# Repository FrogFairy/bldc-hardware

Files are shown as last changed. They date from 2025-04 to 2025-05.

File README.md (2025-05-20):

## Schematic top level
new

## Layout -made with KiCad!-
Layout

## 3D views
3D_1
3d_2

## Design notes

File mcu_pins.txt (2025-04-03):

LED_GREEN PC4 -> PC8
LED_RED PC5 -> PC9
RX_SCL_MOSI PA7 -> PC13
AN_IN PC2 -> PA7
TX_SDA_NSS PA4 -> PD2
TEMP_MOTOR PC0 -> PA4

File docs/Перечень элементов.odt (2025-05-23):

Поз. обозна- чение | Наименование | Кол. | Примечание
C1, C2 | Конденсатор керамический 100 нФ 0603 | 2
C3 | Конденсатор керамический 2.2 мкФ 0603 | 1
C4-C7 | Конденсатор керамический 4.7 нФ 0603 | 4
C8 | Конденсатор керамический 2.2 мкФ 0603 | 1
C9 | Конденсатор керамический 15 пФ 0603 | 1
C10-C12 | Конденсатор керамический 2.2 мкФ 0603 | 3
C13 | Конденсатор керамический 100 нФ 0603 | 1
C14 | Конденсатор керамический 2.2 мкФ 0603 | 1
C15 | Конденсатор керамический 15 пФ 0603 | 1
C16-C22 | Конденсатор керамический 2.2 мкФ 0603 | 7
C23 | Конденсатор керамический 120 пФ 0603 | 1
C24, C25 | Конденсатор керамический 2.2 мкФ 0603 | 2
C26 | Конденсатор керамический 6.8 нФ 0603 | 1
C27 | Конденсатор керамический 22 нФ 0603 | 1
C28 | Конденсатор керамический 2.2 мкФ 0603 | 1
C29-C31 | Конденсатор керамический 10 мкФ 50В 1206 | 3
C32 | Конденсатор керамический 100 нФ 0603 | 1
C33-C35 | Конденсатор крамический 220 нФ X7R 0603 | 3
C36, C37 | Конденсатор керамический 2.2 нФ 0603 | 2
C38 | Конденсатор керамический 2.2 мкФ 0603 | 1
C39 | Конденсатор танталовый 100 мкФ 10В | 1
C40 | Конденсатор керамический 10 мкФ 50В 1206 | 1
C41 | Конденсатор танталовый 100 мкФ 10В | 1
C42, C43 | Конденсатор керамический 10 мкФ 50В 1206 | 2
C44 | Конденсатор керамический 15 мкФ 100В 2220 | 1
C45, C46 | Конденсатор керамический 10 мкФ 50В 1206 | 2
C47 | Конденсатор керамический 15 мкФ 100В 2220 | 1
C48-C53 | Конденсатор керамический 100 нФ 0603 | 6
D1 | Светодиод красный 0603 | 1
D2 | Светодиод зелёный 0603 | 1
D3 | Светодиод жёлтый 0603 | 1
D4 | Диод Шоттки 1N5819 | 1
D5 | Защитный диод SMAJ7.0A | 1
D7 | Диод Шоттки SS24 SMA | 1
J1 | Разъём ST BM10B-GHS-TBT 10-pin | 1
J2 | Разъём USB Type-C | 1
K1 | Разъём сервопривода 3-pin | 1
L1 | Дроссель 22 мкГн 8x5 мм | 1
P1 | Разъём B4B-PH-K(LF)(SN) | 1
P2 | Разъём датчика угла JST-6 | 1
P3 | Клеммник питания B7B-PH-KL | 1
P4 | Клеммник входа "+" | 1
P5 | Клеммник входа "-" | 1
P6 | Клеммник подключения двигателя 3 | 1
P7 | Клеммник подключения двигателя 2 | 1
P8 | Клеммник подключения двигателя 1 | 1
P9 | Разъём питания JST-6 | 1
Q1-Q6 | Транзистор IRFS7530TRLPBF | 6
R1 | Чип резистор 39 кОм 0603 5% | 1
R2 | Чип резистор 2.2 кОм 0603 1% | 1
R6, R7 | Чип резистор 100 Ом 0603 1% | 2
R8, R9 | Чип резистор 2.2 кОм 0603 1% | 2
R10, R11 | Резистор-шунт 0 Ом 2 Вт | 2
R12 | Резистор-перемычка 0 Ом 0603 | 1
R13, R14 | Чип резистор 10 кОм 0603 1% | 2
R15-R17 | Чип резистор 2.2 кОм 0603 1% | 3
R18-R20 | Чип резистор 10 кОм 0603 1% | 3
R21 | Термистор NTC 10 кОм 0603 | 1
R22 | Чип резистор 10 кОм 0603 1% | 1
R23 | Чип резистор 18 кОм 0603 1% | 1
R24 | Чип резистор 3.3 кОм 0603 1% | 1
R25 | Чип резистор 10 кОм 0603 1% | 1
R26 | Чип резистор 15 кОм 0603 5% | 1
R27 | Чип резистор 220 кОм 0603 5% | 1
R28 | Чип резистор 1 МОм 0603 1% | 1
R29-R32 | Чип резистор 100 Ом 0603 1% | 4
R33 | Чип резистор 39 кОм 0603 5% | 1
R34 | Чип резистор 2.2 кОм 0603 1% | 1
R35 | Чип резистор 39 кОм 0603 5% | 1
R36 | Чип резистор 2.2 кОм 0603 1% | 1
R37 | Чип резистор 39 кОм 0603 5% | 1
R38 | Чип резистор 2.2 кОм 0603 1% | 1
R39, R40 | Чип резистор 4.7 Ом 0603 1% | 2
R41 | Чип резистор 39 кОм 0603 5% | 1
R42, R43 | Чип резистор 4.7 Ом 0603 1% | 2
R44 | Чип резистор 39 кОм 0603 5% | 1
R45, R46 | Чип резистор 4.7 Ом 0603 1% | 2
R47 | Чип резистор 39 кОм 0603 5% | 1
R48-R53 | Чип резистор 18 кОм 0603 1% | 6
R54-R59 | Чип резистор 2.2 кОм 0603 1% | 6
R60-R65 | Чип резистор 360 Ом 0603 1% | 6
R66-R71 | Чип резистор 16 Ом 2512 1% | 6
R103, R104 | Чип резистор 5.1 кОм 0603 | 2
U1 | CAN приёмопередатчик SN65HVD232DR | 1
U2 | Микроконтроллер STM32F40X LQFP64 | 1
U3 | Драйвер двигателя DRV8302DCA | 1
U4 | Стабилизатор напряжения TC2117 | 1
U11-U16 | Опто твердотельное реле CPC1002N 0603 | 6
X2 | Кварцевый резонатор 8 МГц 10ppm | 1

BLDC Driver 4.11 Перечень элементов Benjamin Vedder Лит. Лист 1 Листов 4 Разраб. Пров. Н. контр. Утв. Top level Изм. Лист № докум. Подп. Дата Инв. № подл. Подп. и дата Взам. инв. № Инв. № дубл. Подп. и дата Копировал Формат А4

BLDC Driver 4.11 Перечень элементов Benjamin Vedder Лит. Лист 0 Листов 4 Разраб. Пров. Н. контр. Утв. Top level Изм. Лист № докум. Подп. Дата Инв. № подл. Подп. и дата Взам. инв. № Инв. № дубл. Подп. и дата Справ. № Перв. примен. Копировал Формат А4

BLDC Driver 4.11 Перечень элементов Benjamin Vedder Лит. Лист 0 Листов 4 Разраб. Пров. Н. контр. Утв. Top level Изм. Лист № докум. Подп. Дата Инв. № подл. Подп. и дата Взам. инв. № Инв. № дубл. Подп. и дата Копировал Формат А4

Лист 4 Изм. Лист № докум. Подп. Дата Инв. № подл. Подп. и дата Взам. инв. № Инв. № дубл. Подп. и дата Копировал Формат А4

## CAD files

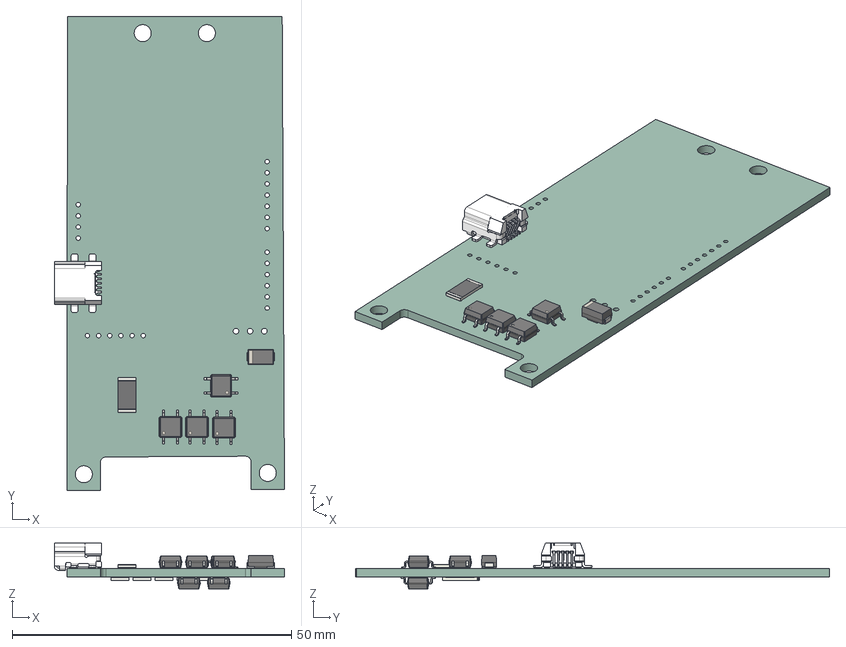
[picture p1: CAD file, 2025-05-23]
design/BLDC_4.step
41.2 x 85.0 x 8.23 mm
UX60R-MB-5ST-STEP
R_2512_6332Metric x 6
SOP-4_3.8x4.1mm_P2.54mm x 6
D_SMA
BLDC_4_PCB

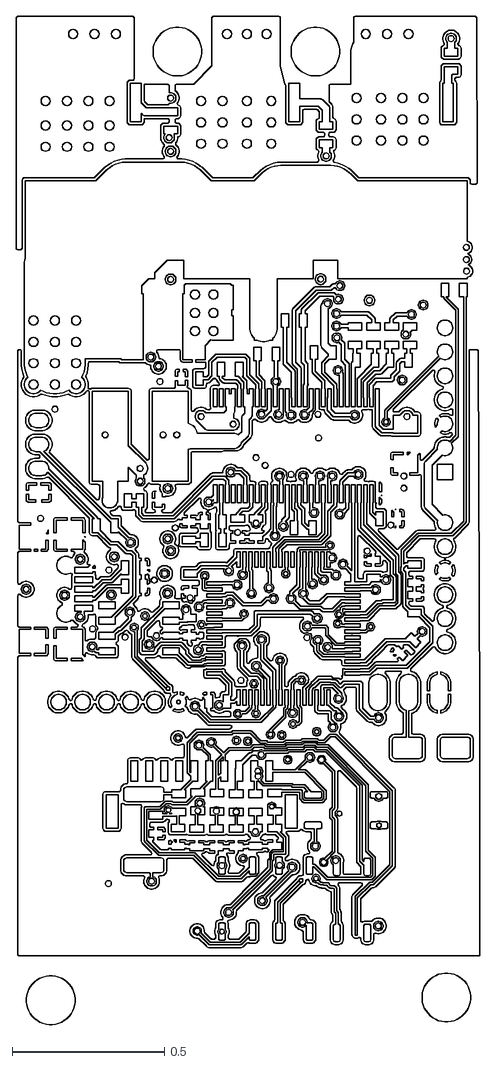
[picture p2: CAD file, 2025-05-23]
design/Gerber/BLDC_4-F_Cu.dxf
1.52 x 3.31

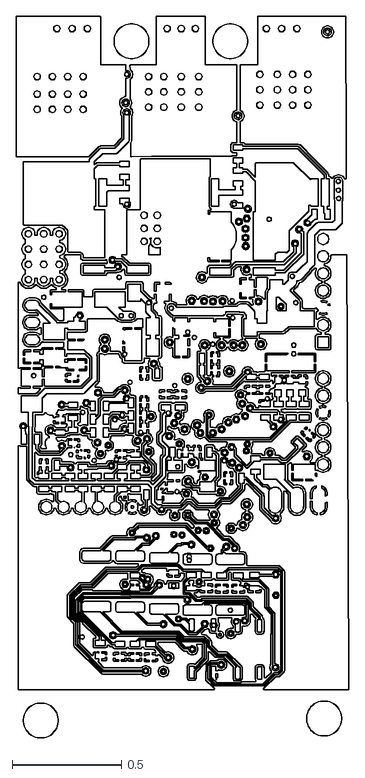
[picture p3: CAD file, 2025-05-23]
design/Gerber/BLDC_4-B_Cu.dxf
1.53 x 3.31

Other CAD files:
design/BLDC_4.stl
design/Gerber/BLDC_4-F_Silkscreen.dxf

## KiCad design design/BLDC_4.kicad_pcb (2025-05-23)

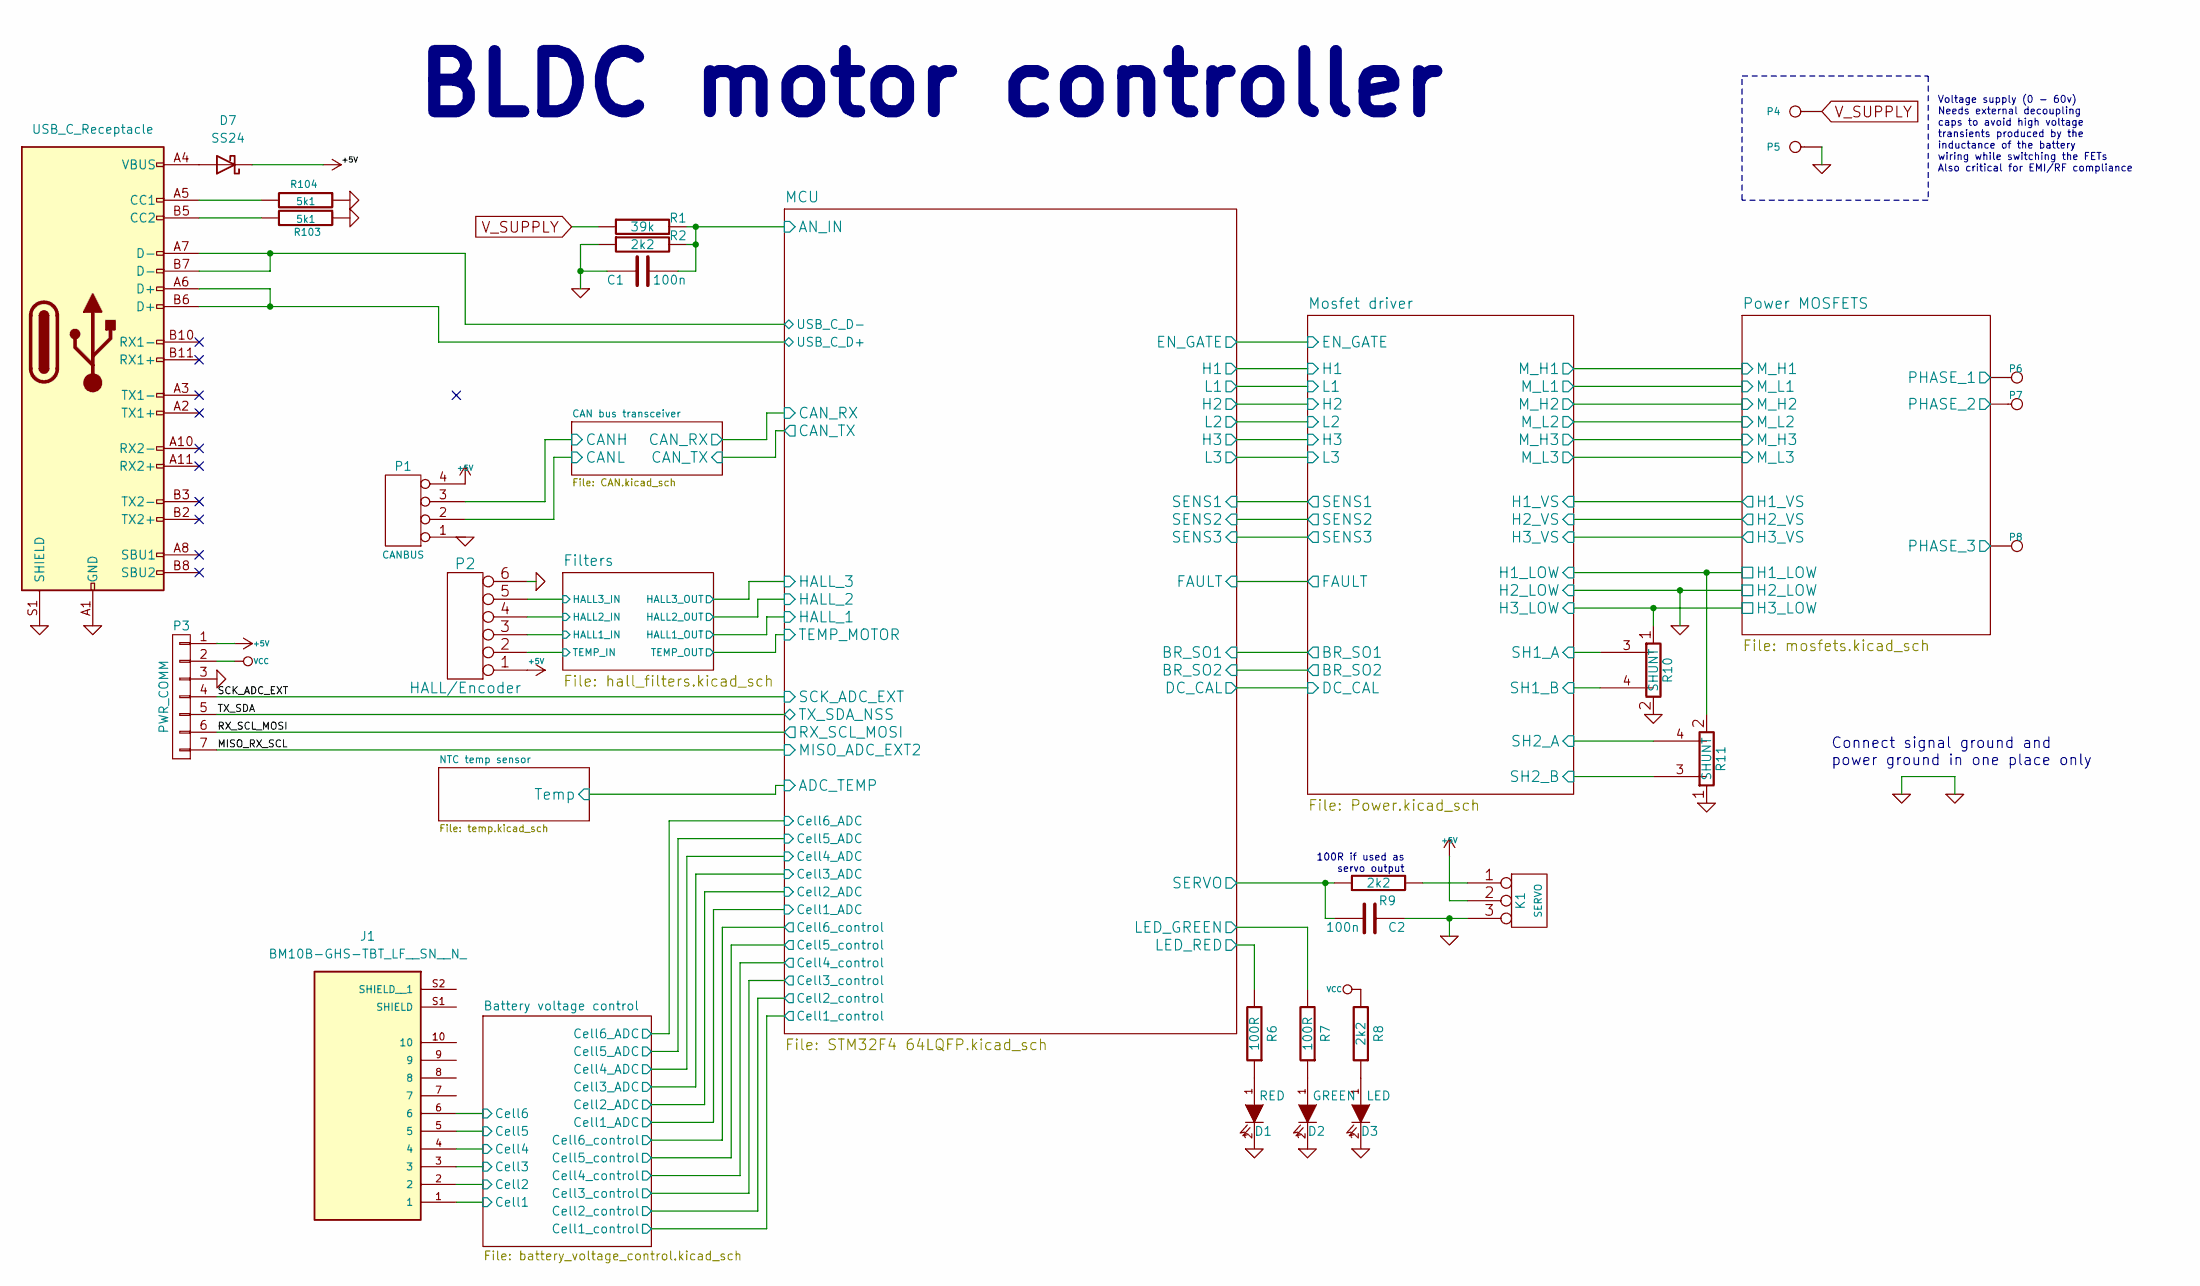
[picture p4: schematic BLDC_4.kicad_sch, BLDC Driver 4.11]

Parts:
C1, C2: 100n; SMD-0603_c
D1: RED; LED-0603
D2: GREEN; LED-0603
D3: LED; LED-0603
D7: SS24; D_SMA
J1: BM10B-GHS-TBT_LF__SN__N_; JST_BM10B-GHS-TBT_LF__SN__N_; PARTREV N/A
J2: USB_C_Receptacle
K1: SERVO; pinhead-1X03
P1: CANBUS; b4b-ph-kl
P2: HALL/Encoder; MICRO_JST_6
P3: PWR_COMM; b7b-ph-kl
P4: IN+; 1PAD_4x5mm
P5: IN-; 1PAD_4x5mm
P6: MOTOR3; 1PAD_4x5mm
P7: MOTOR2; 1PAD_4x5mm
P8: MOTOR1; 1PAD_4x5mm
R1: 39k; SMD-0603_r
R2, R8, R9: 2k2; SMD-0603_r
R6, R7: 100R; SMD-0603_r
R10, R11: SHUNT; WSLP2726
R103, R104: 5k1; SMD-0603_r

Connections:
+5V: D7.1 (K), K1.2 (PM), P1.4, P2.1, P3.1; also elsewhere on the board
/Battery voltage control/Cell1: J1.1; also elsewhere on the board
/Battery voltage control/Cell2: J1.2; also elsewhere on the board
/Battery voltage control/Cell3: J1.3; also elsewhere on the board
/Battery voltage control/Cell4: J1.4; also elsewhere on the board
/Battery voltage control/Cell5: J1.5; also elsewhere on the board
/Battery voltage control/Cell6: J1.6; also elsewhere on the board
/CAN bus transceiver/CANH: P1.3; also elsewhere on the board
/CAN bus transceiver/CANL: P1.2; also elsewhere on the board
/Filters/HALL1_IN: P2.3; also elsewhere on the board
/Filters/HALL2_IN: P2.4; also elsewhere on the board
/Filters/HALL3_IN: P2.5; also elsewhere on the board
/Filters/TEMP_MOTOR: P2.2; also elsewhere on the board
/MCU/AN_IN: C1.2, R1.2, R2.2; also elsewhere on the board
/MCU/LED_GREEN: R7.2; also elsewhere on the board
/MCU/LED_RED: R6.2; also elsewhere on the board
/MCU/SERVO: C2.2, R9.1; also elsewhere on the board
/MISO_RX_SCL: P3.7; also elsewhere on the board
/Mosfet driver/H1_LOW: R11.2; also elsewhere on the board
/Mosfet driver/H1_VS: P6.1; also elsewhere on the board
/Mosfet driver/H2_VS: P7.1; also elsewhere on the board
/Mosfet driver/H3_LOW: R10.1; also elsewhere on the board
/Mosfet driver/H3_VS: P8.1; also elsewhere on the board
/Mosfet driver/SH1_A: R10.3; also elsewhere on the board
/Mosfet driver/SH1_B: R10.4; also elsewhere on the board
/Mosfet driver/SH2_A: R11.4; also elsewhere on the board
/Mosfet driver/SH2_B: R11.3; also elsewhere on the board
/RX_SCL_MOSI: P3.6; also elsewhere on the board
/SCK_ADC_EXT: P3.4; also elsewhere on the board
/TX_SDA: P3.5; also elsewhere on the board
GND: C1.1, C2.1, D1.2 (K), D2.2 (K), D3.2 (K), J2.A1 (GND), J2.A12 (GND), J2.B1 (GND), J2.B12 (GND), J2.S1 (SHIELD), K1.3, P1.1, P2.6, P3.3, P5.1, R2.1, R10.2, R11.1, R103.1, R104.1; also elsewhere on the board
unnamed: D1.1 (A), R6.1
unnamed: D2.1 (A), R7.1
unnamed: D3.1 (A), R8.1
unnamed: D7.2 (A), J2.A4 (VBUS), J2.A9 (VBUS), J2.B4 (VBUS), J2.B9 (VBUS)
unnamed: J2.A5 (CC1), R104.2
unnamed: J2.B5 (CC2), R103.2
unnamed: J2.A6 (D+), J2.B6 (D+)
unnamed: J2.A7 (D-), J2.B7 (D-)
unnamed: K1.1, R9.2
VCC: P3.2, R8.2; also elsewhere on the board
V_SUPPLY: P4.1, R1.1; also elsewhere on the board

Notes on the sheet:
Voltage supply (0 - 60v) Needs external decoupling caps to avoid high voltage transients produced by the inductance of the battery wiring while switching the FETs Also critical for EMI/RF compliance
Connect signal ground and power ground in one place only
BLDC motor controller
100R if used as servo output

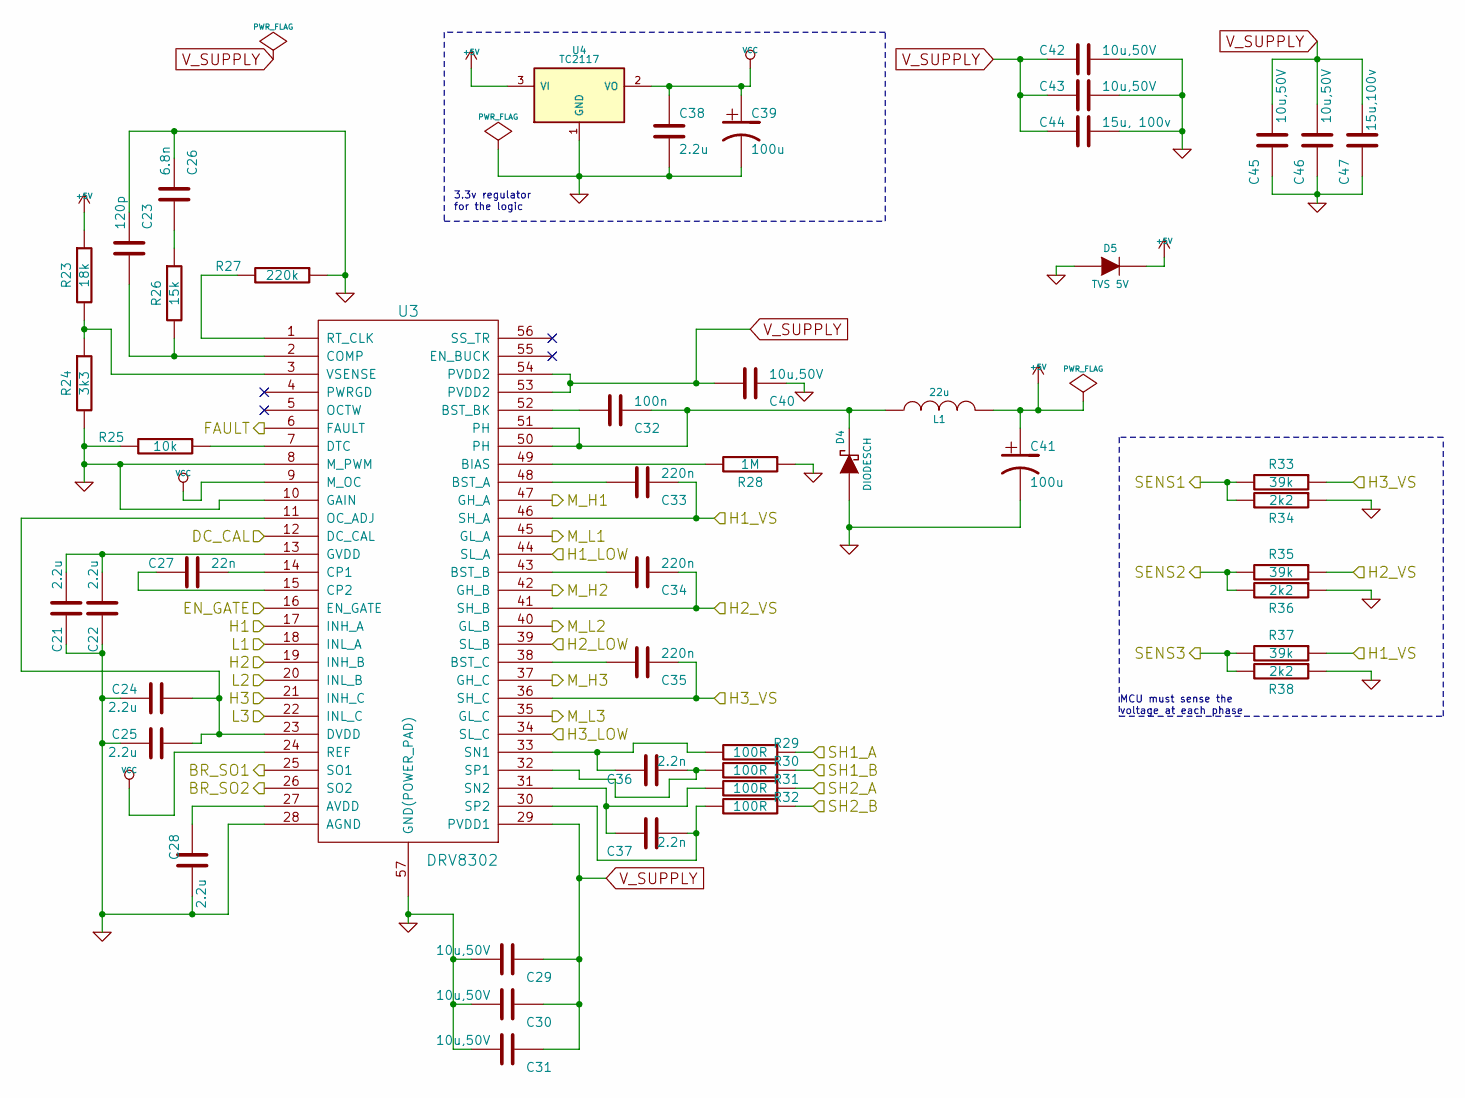
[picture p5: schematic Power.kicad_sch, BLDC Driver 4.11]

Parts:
C21, C22, C24, C25, C28, C38: 2.2u; SMD-0603_c
C23: 120p; SMD-0603_c
C26: 6.8n; SMD-0603_c
C27: 22n; SMD-0603_c
C29, C30, C31, C40, C42, C43, C45, C46: 10u,50V; SMD-1206
C32: 100n; SMD-0603_c
C33, C34, C35: 220n; SMD-0603_c
C36, C37: 2.2n; SMD-0603_c
C39, C41: 100u; c_tant_B
C44: 15u, 100v; c_2220
C47: 15u,100v; c_2220
D4: DIODESCH; SMA_Handsoldering
D5: TVS 5V; do214ac
L1: 22u; inductor_smd_8x5mm
R23: 18k; SMD-0603_r
R24: 3k3; SMD-0603_r
R25: 10k; SMD-0603_r
R26: 15k; SMD-0603_r
R27: 220k; SMD-0603_r
R28: 1M; SMD-0603_r
R29, R30, R31, R32: 100R; SMD-0603_r
R33, R35, R37: 39k; SMD-0603_r
R34, R36, R38: 2k2; SMD-0603_r
U3: DRV8302; TSSOP-56-PP
U4: TC2117; SOT-223

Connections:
+5V: C41.1, D5.2 (K), L1.2, R23.1, U4.3 (VI); also elsewhere on the board
/MCU/BR_SO1: U3.25 (SO1); also elsewhere on the board
/MCU/BR_SO2: U3.26 (SO2); also elsewhere on the board
/MCU/DC_CAL: U3.12 (DC_CAL); also elsewhere on the board
/MCU/EN_GATE: U3.16 (EN_GATE); also elsewhere on the board
/MCU/FAULT: U3.6 (FAULT); also elsewhere on the board
/MCU/H1: U3.17 (INH_A); also elsewhere on the board
/MCU/H2: U3.19 (INH_B); also elsewhere on the board
/MCU/H3: U3.21 (INH_C); also elsewhere on the board
/MCU/L1: U3.18 (INL_A); also elsewhere on the board
/MCU/L2: U3.20 (INL_B); also elsewhere on the board
/MCU/L3: U3.22 (INL_C); also elsewhere on the board
/MCU/SENS1: R33.2, R34.2; also elsewhere on the board
/MCU/SENS2: R35.2, R36.2; also elsewhere on the board
/MCU/SENS3: R37.2, R38.2; also elsewhere on the board
/Mosfet driver/H1_LOW: U3.44 (SL_A); also elsewhere on the board
/Mosfet driver/H1_VS: C33.1, R37.1, U3.46 (SH_A); also elsewhere on the board
/Mosfet driver/H2_VS: C34.1, R35.1, U3.41 (SH_B); also elsewhere on the board
/Mosfet driver/H3_LOW: U3.34 (SL_C); also elsewhere on the board
/Mosfet driver/H3_VS: C35.1, R33.1, U3.36 (SH_C); also elsewhere on the board
/Mosfet driver/M_H1: U3.47 (GH_A); also elsewhere on the board
/Mosfet driver/M_H2: U3.42 (GH_B); also elsewhere on the board
/Mosfet driver/M_H3: U3.37 (GH_C); also elsewhere on the board
/Mosfet driver/M_L1: U3.45 (GL_A); also elsewhere on the board
/Mosfet driver/M_L2: U3.40 (GL_B); also elsewhere on the board
/Mosfet driver/M_L3: U3.35 (GL_C); also elsewhere on the board
/Mosfet driver/SH1_A: R29.1; also elsewhere on the board
/Mosfet driver/SH1_B: R30.1; also elsewhere on the board
/Mosfet driver/SH2_A: R31.1; also elsewhere on the board
/Mosfet driver/SH2_B: R32.1; also elsewhere on the board
GND: C21.2, C22.2, C23.1, C24.1, C25.1, C26.1, C28.1, C29.2, C30.2, C31.2, C38.2, C39.2, C40.1, C41.2, C42.1, C43.1, C44.1, C45.1, C46.1, C47.1, D4.1 (A), D5.1 (A), R24.2, R25.2, R27.1, R28.1, R34.1, R36.1, R38.1, U3.8 (M_PWM), U3.10 (GAIN), U3.28 (AGND), U3.39 (SL_B), U3.57 (GND(POWER_PAD)), U4.1 (GND); also elsewhere on the board
unnamed: C26.2, R26.1
unnamed: C32.1, D4.2 (K), L1.1, U3.50 (PH), U3.51 (PH)
unnamed: C28.2, U3.27 (AVDD)
unnamed: R28.2, U3.49 (BIAS)
unnamed: C33.2, U3.48 (BST_A)
unnamed: C34.2, U3.43 (BST_B)
unnamed: C32.2, U3.52 (BST_BK)
unnamed: C35.2, U3.38 (BST_C)
unnamed: C23.2, R26.2, U3.2 (COMP)
unnamed: C27.1, U3.14 (CP1)
unnamed: C27.2, U3.15 (CP2)
unnamed: R25.1, U3.7 (DTC)
unnamed: C24.2, C25.2, U3.11 (OC_ADJ), U3.23 (DVDD)
unnamed: C21.1, C22.1, U3.13 (GVDD)
unnamed: R27.2, U3.1 (RT_CLK)
unnamed: C36.1, R29.2, U3.33 (SN1)
unnamed: C37.1, R31.2, U3.31 (SN2)
unnamed: C36.2, R30.2, U3.32 (SP1)
unnamed: C37.2, R32.2, U3.30 (SP2)
unnamed: R23.2, R24.1, U3.3 (VSENSE)
VCC: C38.1, C39.1, U3.9 (M_OC), U3.24 (REF), U4.2 (VO); also elsewhere on the board
V_SUPPLY: C29.1, C30.1, C31.1, C40.2, C42.2, C43.2, C44.2, C45.2, C46.2, C47.2, U3.29 (PVDD1), U3.53 (PVDD2), U3.54 (PVDD2); also elsewhere on the board

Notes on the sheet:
MCU must sense the voltage at each phase
3.3v regulator for the logic

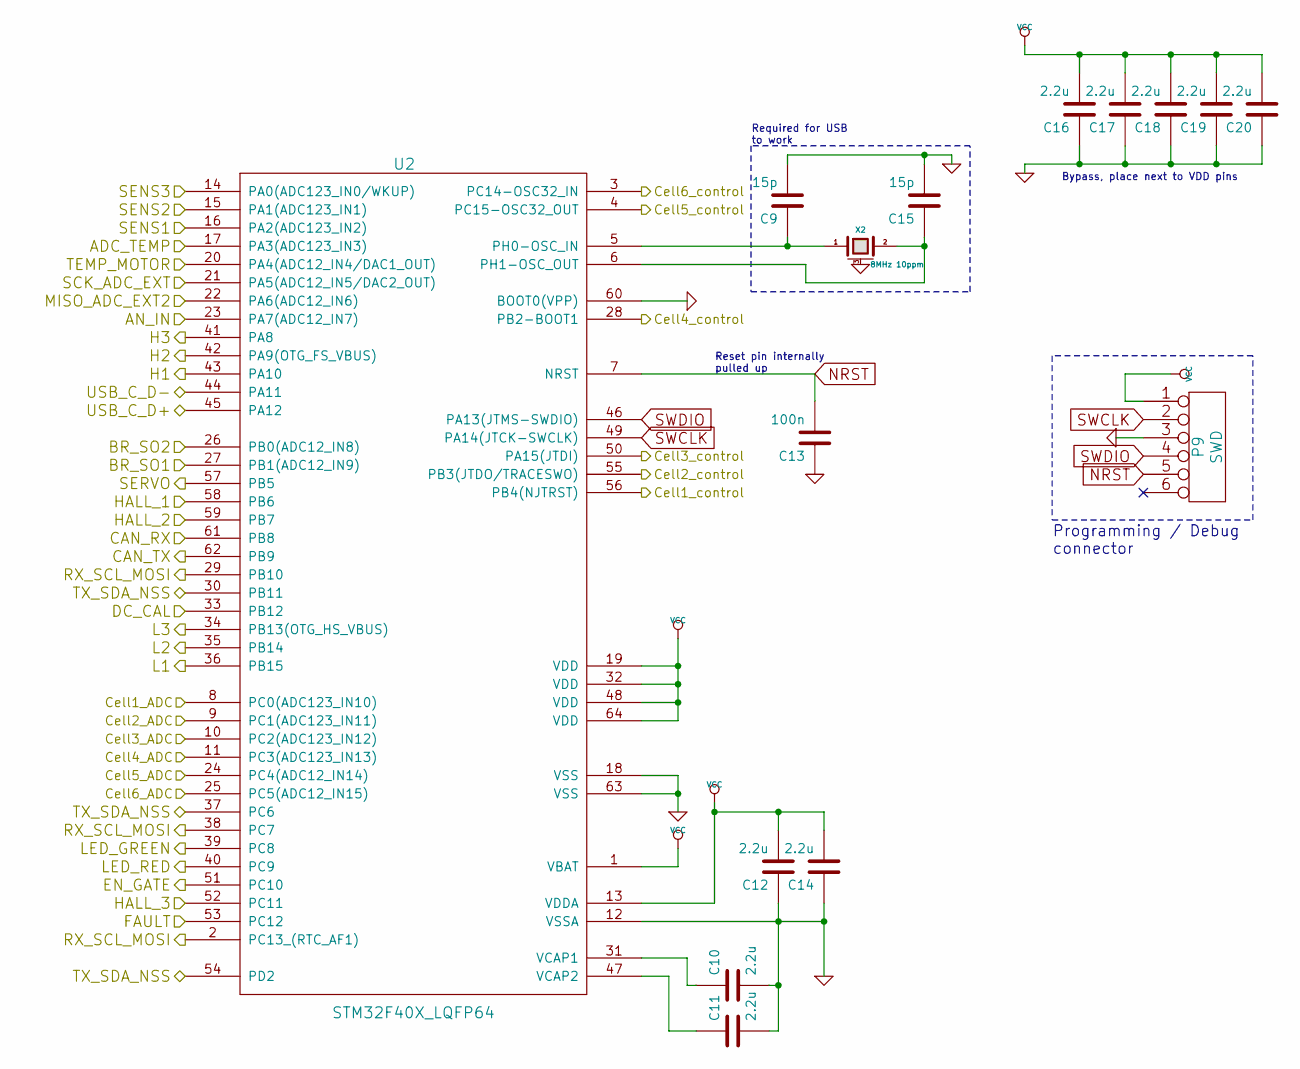
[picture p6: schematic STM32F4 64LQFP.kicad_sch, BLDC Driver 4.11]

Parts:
C9, C15: 15p; SMD-0603_c
C10, C11, C12, C14, C16, C17, C18, C19, C20: 2.2u; SMD-0603_c
C13: 100n; SMD-0603_c
P9: SWD; MICRO_JST_6
U2: STM32F40X_LQFP64; lqfp64_pad_mod
X2: 8MHz 10ppm; Crystal_5x3mm; mfg# ABM3B-8.0-10-1UT

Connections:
/Battery voltage control/Cell1_ADC: U2.8 (PC0(ADC123_IN10)); also elsewhere on the board
/Battery voltage control/Cell1_control: U2.56 (PB4(NJTRST)); also elsewhere on the board
/Battery voltage control/Cell2_ADC: U2.9 (PC1(ADC123_IN11)); also elsewhere on the board
/Battery voltage control/Cell2_control: U2.55 (PB3(JTDO/TRACESWO)); also elsewhere on the board
/Battery voltage control/Cell3_ADC: U2.10 (PC2(ADC123_IN12)); also elsewhere on the board
/Battery voltage control/Cell3_control: U2.50 (PA15(JTDI)); also elsewhere on the board
/Battery voltage control/Cell4_ADC: U2.11 (PC3(ADC123_IN13)); also elsewhere on the board
/Battery voltage control/Cell4_control: U2.28 (PB2-BOOT1); also elsewhere on the board
/Battery voltage control/Cell5_ADC: U2.24 (PC4(ADC12_IN14)); also elsewhere on the board
/Battery voltage control/Cell5_control: U2.4 (PC15-OSC32_OUT); also elsewhere on the board
/Battery voltage control/Cell6_ADC: U2.25 (PC5(ADC12_IN15)); also elsewhere on the board
/Battery voltage control/Cell6_control: U2.3 (PC14-OSC32_IN); also elsewhere on the board
/CAN bus transceiver/CAN_RX: U2.61 (PB8); also elsewhere on the board
/CAN bus transceiver/CAN_TX: U2.62 (PB9); also elsewhere on the board
/Filters/HALL1_OUT: U2.58 (PB6); also elsewhere on the board
/Filters/HALL2_OUT: U2.59 (PB7); also elsewhere on the board
/Filters/HALL3_OUT: U2.52 (PC11); also elsewhere on the board
/Filters/TEMP_MOTOR: U2.20 (PA4(ADC12_IN4/DAC1_OUT)); also elsewhere on the board
/MCU/ADC_TEMP: U2.17 (PA3(ADC123_IN3)); also elsewhere on the board
/MCU/AN_IN: U2.23 (PA7(ADC12_IN7)); also elsewhere on the board
/MCU/BR_SO1: U2.27 (PB1(ADC12_IN9)); also elsewhere on the board
/MCU/BR_SO2: U2.26 (PB0(ADC12_IN8)); also elsewhere on the board
/MCU/DC_CAL: U2.33 (PB12); also elsewhere on the board
/MCU/EN_GATE: U2.51 (PC10); also elsewhere on the board
/MCU/FAULT: U2.53 (PC12); also elsewhere on the board
/MCU/H1: U2.43 (PA10); also elsewhere on the board
/MCU/H2: U2.42 (PA9(OTG_FS_VBUS)); also elsewhere on the board
/MCU/H3: U2.41 (PA8); also elsewhere on the board
/MCU/L1: U2.36 (PB15); also elsewhere on the board
/MCU/L2: U2.35 (PB14); also elsewhere on the board
/MCU/L3: U2.34 (PB13(OTG_HS_VBUS)); also elsewhere on the board
/MCU/LED_GREEN: U2.39 (PC8); also elsewhere on the board
/MCU/LED_RED: U2.40 (PC9); also elsewhere on the board
/MCU/SENS1: U2.16 (PA2(ADC123_IN2)); also elsewhere on the board
/MCU/SENS2: U2.15 (PA1(ADC123_IN1)); also elsewhere on the board
/MCU/SENS3: U2.14 (PA0(ADC123_IN0/WKUP)); also elsewhere on the board
/MCU/SERVO: U2.57 (PB5); also elsewhere on the board
/MCU/USB_C_D+: U2.45 (PA12)
/MCU/USB_C_D-: U2.44 (PA11)
/MISO_RX_SCL: U2.22 (PA6(ADC12_IN6)); also elsewhere on the board
/RX_SCL_MOSI: U2.2 (PC13_(RTC_AF1)), U2.29 (PB10), U2.38 (PC7); also elsewhere on the board
/SCK_ADC_EXT: U2.21 (PA5(ADC12_IN5/DAC2_OUT)); also elsewhere on the board
/TX_SDA: U2.30 (PB11), U2.37 (PC6), U2.54 (PD2); also elsewhere on the board
GND: C9.2, C10.2, C11.2, C12.1, C13.1, C14.1, C15.2, C16.1, C17.1, C18.1, C19.1, C20.1, P9.3, U2.12 (VSSA), U2.18 (VSS), U2.60 (BOOT0(VPP)), U2.63 (VSS), X2.3 (case); also elsewhere on the board
NRST: C13.2, P9.5, U2.7 (NRST)
unnamed: C9.1, U2.5 (PH0-OSC_IN), X2.1
unnamed: C15.1, U2.6 (PH1-OSC_OUT), X2.2
unnamed: C10.1, U2.31 (VCAP1)
unnamed: C11.1, U2.47 (VCAP2)
SWCLK: P9.2, U2.49 (PA14(JTCK-SWCLK))
SWDIO: P9.4, U2.46 (PA13(JTMS-SWDIO))
VCC: C12.2, C14.2, C16.2, C17.2, C18.2, C19.2, C20.2, P9.1, U2.1 (VBAT), U2.13 (VDDA), U2.19 (VDD), U2.32 (VDD), U2.48 (VDD), U2.64 (VDD); also elsewhere on the board

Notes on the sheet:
Reset pin internally pulled up
Required for USB to work
Programming / Debug connector
Bypass, place next to VDD pins

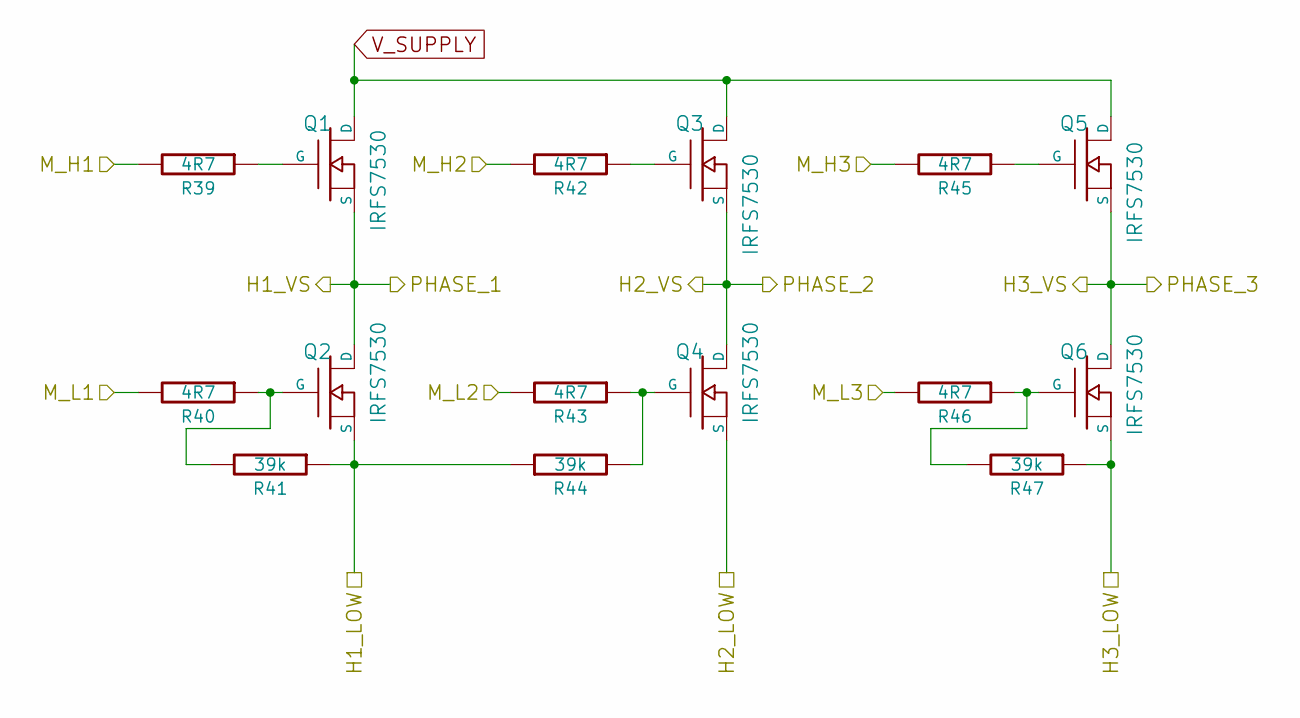
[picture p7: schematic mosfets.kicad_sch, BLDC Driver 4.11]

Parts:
Q1, Q2, Q3, Q4, Q5, Q6: IRFS7530; D2PAK-7-GDS
R39, R40, R42, R43, R45, R46: 4R7; SMD-0603_r
R41, R44, R47: 39k; SMD-0603_r

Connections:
/Mosfet driver/H1_LOW: Q2.S, R41.1, R44.1; also elsewhere on the board
/Mosfet driver/H1_VS: Q1.S, Q2.D; also elsewhere on the board
/Mosfet driver/H2_VS: Q3.S, Q4.D; also elsewhere on the board
/Mosfet driver/H3_LOW: Q6.S, R47.1; also elsewhere on the board
/Mosfet driver/H3_VS: Q5.S, Q6.D; also elsewhere on the board
/Mosfet driver/M_H1: R39.2; also elsewhere on the board
/Mosfet driver/M_H2: R42.2; also elsewhere on the board
/Mosfet driver/M_H3: R45.2; also elsewhere on the board
/Mosfet driver/M_L1: R40.2; also elsewhere on the board
/Mosfet driver/M_L2: R43.2; also elsewhere on the board
/Mosfet driver/M_L3: R46.2; also elsewhere on the board
GND: Q4.S; also elsewhere on the board
unnamed: Q1.G, R39.1
unnamed: Q2.G, R40.1, R41.2
unnamed: Q3.G, R42.1
unnamed: Q4.G, R43.1, R44.2
unnamed: Q5.G, R45.1
unnamed: Q6.G, R46.1, R47.2
V_SUPPLY: Q1.D, Q3.D, Q5.D; also elsewhere on the board

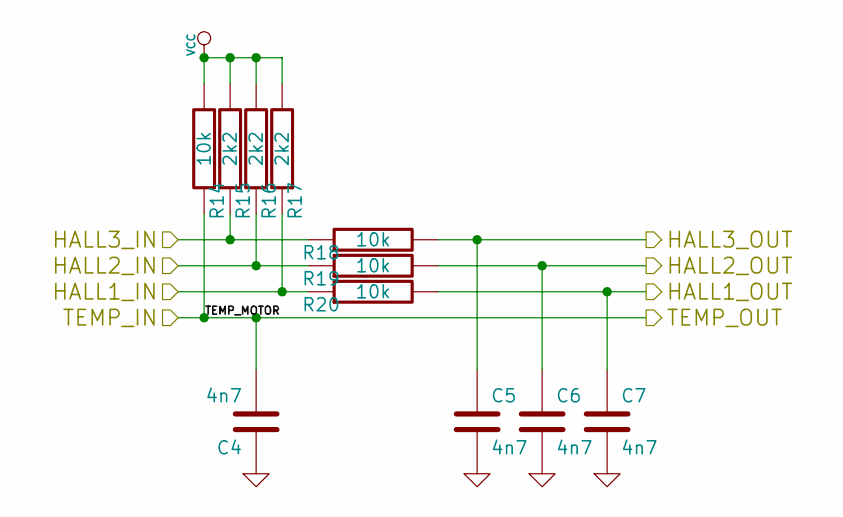
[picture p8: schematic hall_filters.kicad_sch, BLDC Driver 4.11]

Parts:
C4, C5, C6, C7: 4n7; SMD-0603_c
R14, R18, R19, R20: 10k; SMD-0603_r
R15, R16, R17: 2k2; SMD-0603_r

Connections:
/Filters/HALL1_IN: R17.1, R20.1; also elsewhere on the board
/Filters/HALL1_OUT: C7.1, R20.2; also elsewhere on the board
/Filters/HALL2_IN: R16.1, R19.1; also elsewhere on the board
/Filters/HALL2_OUT: C6.1, R19.2; also elsewhere on the board
/Filters/HALL3_IN: R15.1, R18.1; also elsewhere on the board
/Filters/HALL3_OUT: C5.1, R18.2; also elsewhere on the board
/Filters/TEMP_MOTOR: C4.2, R14.1; also elsewhere on the board
GND: C4.1, C5.2, C6.2, C7.2; also elsewhere on the board
VCC: R14.2, R15.2, R16.2, R17.2; also elsewhere on the board

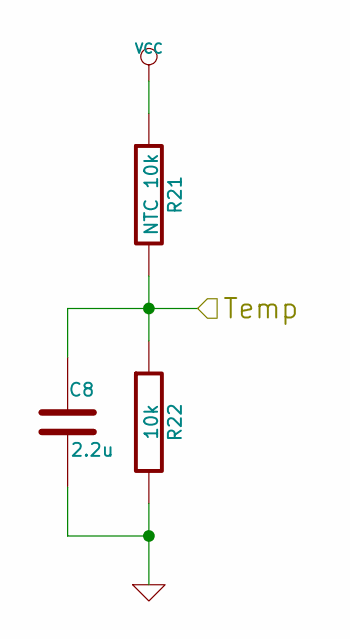
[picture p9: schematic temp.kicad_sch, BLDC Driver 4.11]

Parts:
C8: 2.2u; SMD-0603_c
R21: NTC 10k; SMD-0603_r
R22: 10k; SMD-0603_r

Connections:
/MCU/ADC_TEMP: C8.1, R21.2, R22.1; also elsewhere on the board
GND: C8.2, R22.2; also elsewhere on the board
VCC: R21.1; also elsewhere on the board

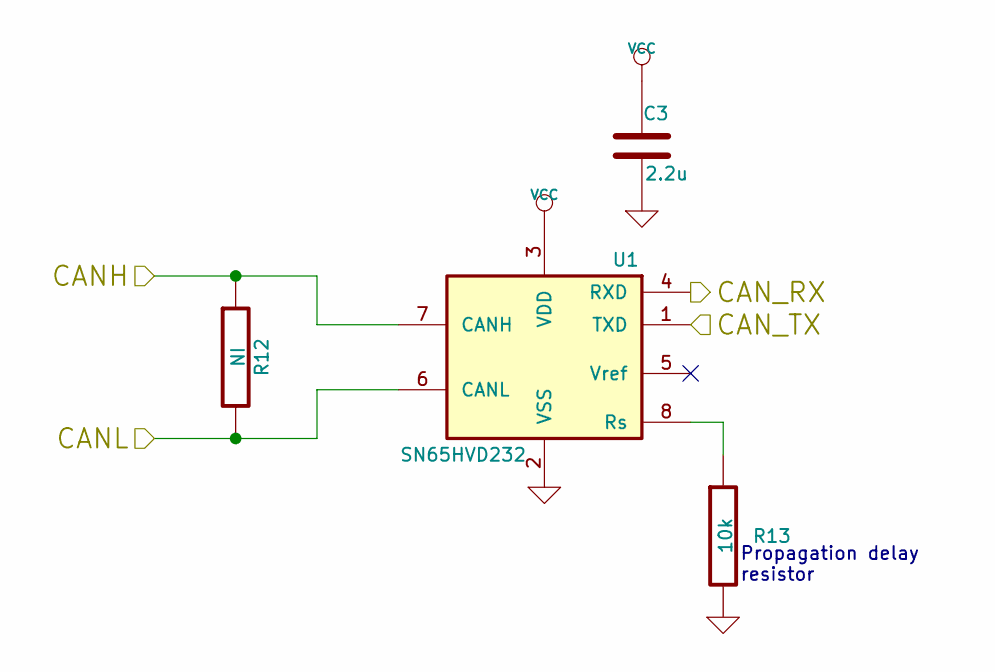
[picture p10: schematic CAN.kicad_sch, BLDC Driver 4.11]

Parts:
C3: 2.2u; SMD-0603_c
R12: NI; SMD-0603_r
R13: 10k; SMD-0603_r
U1: SN65HVD232; SOIC-8-W

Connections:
/CAN bus transceiver/CANH: R12.1, U1.7 (CANH); also elsewhere on the board
/CAN bus transceiver/CANL: R12.2, U1.6 (CANL); also elsewhere on the board
/CAN bus transceiver/CAN_RX: U1.4 (RXD); also elsewhere on the board
/CAN bus transceiver/CAN_TX: U1.1 (TXD); also elsewhere on the board
GND: C3.2, R13.2, U1.2 (VSS); also elsewhere on the board
unnamed: R13.1, U1.8 (Rs)
VCC: C3.1, U1.3 (VDD); also elsewhere on the board

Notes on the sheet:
Propagation delay resistor

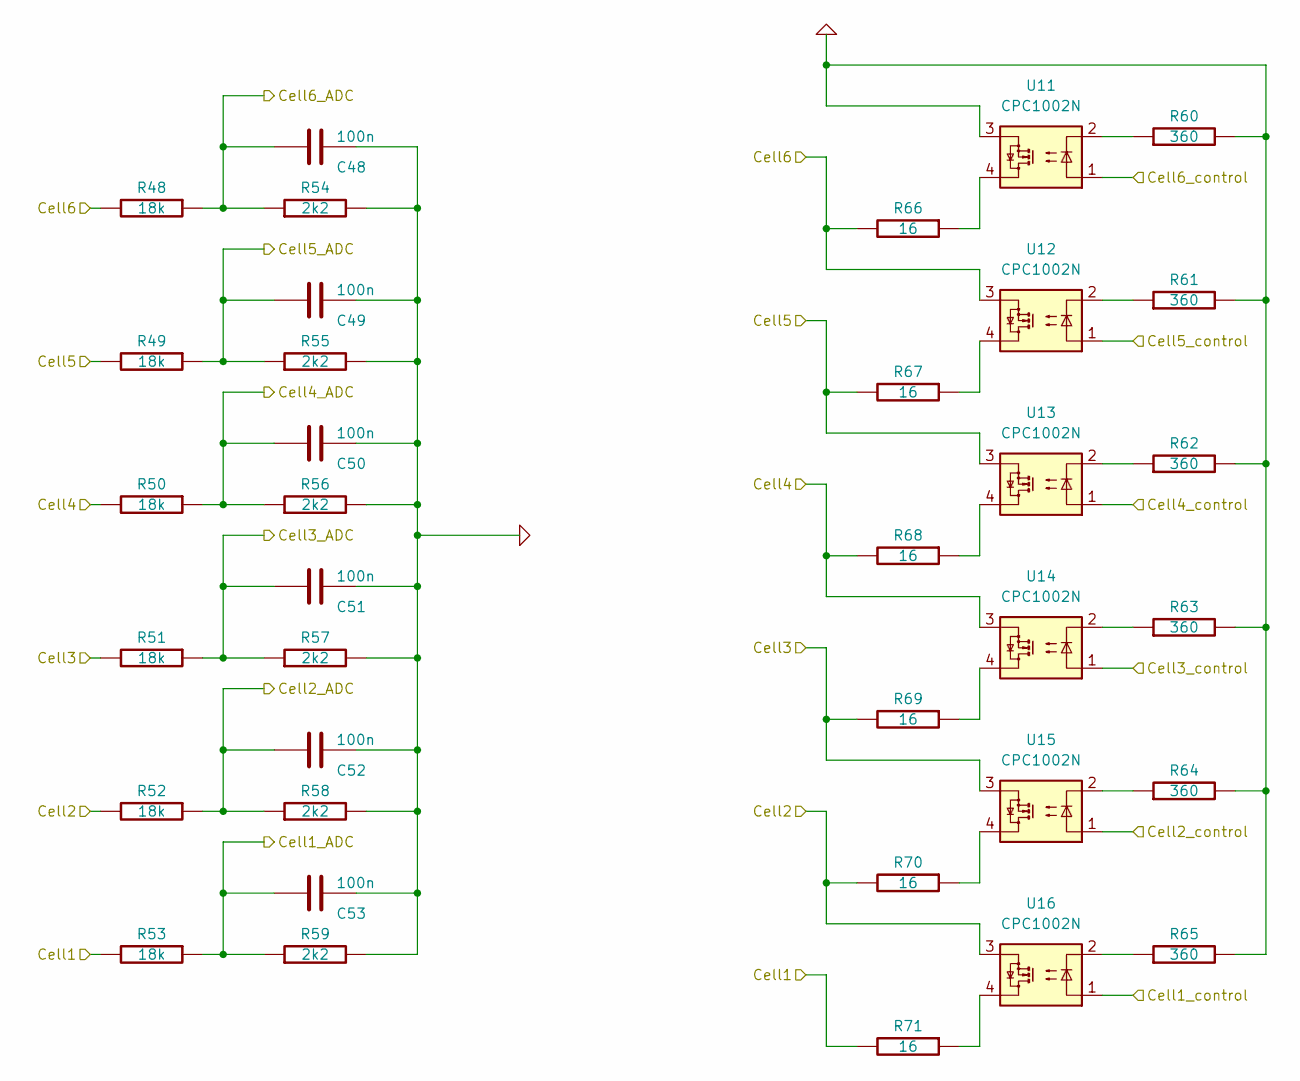
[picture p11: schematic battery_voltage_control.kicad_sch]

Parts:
C48, C49, C50, C51, C52, C53: 100n; SMD-0603_c
R48, R49, R50, R51, R52, R53: 18k; SMD-0603_r
R54, R55, R56, R57, R58, R59: 2k2; SMD-0603_r
R60, R61, R62, R63, R64, R65: 360; SMD-0603_r
R66, R67, R68, R69, R70, R71: 16; R_2512_6332Metric
U11, U12, U13, U14, U15, U16: CPC1002N; SOP-4_3.8x4.1mm_P2.54mm

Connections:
/Battery voltage control/Cell1: R53.2, R71.2; also elsewhere on the board
/Battery voltage control/Cell1_ADC: C53.2, R53.1, R59.1; also elsewhere on the board
/Battery voltage control/Cell1_control: U16.1; also elsewhere on the board
/Battery voltage control/Cell2: R52.2, R70.2, U16.3; also elsewhere on the board
/Battery voltage control/Cell2_ADC: C52.2, R52.1, R58.1; also elsewhere on the board
/Battery voltage control/Cell2_control: U15.1; also elsewhere on the board
/Battery voltage control/Cell3: R51.2, R69.2, U15.3; also elsewhere on the board
/Battery voltage control/Cell3_ADC: C51.2, R51.1, R57.1; also elsewhere on the board
/Battery voltage control/Cell3_control: U14.1; also elsewhere on the board
/Battery voltage control/Cell4: R50.2, R68.2, U14.3; also elsewhere on the board
/Battery voltage control/Cell4_ADC: C50.2, R50.1, R56.1; also elsewhere on the board
/Battery voltage control/Cell4_control: U13.1; also elsewhere on the board
/Battery voltage control/Cell5: R49.2, R67.2, U13.3; also elsewhere on the board
/Battery voltage control/Cell5_ADC: C49.2, R49.1, R55.1; also elsewhere on the board
/Battery voltage control/Cell5_control: U12.1; also elsewhere on the board
/Battery voltage control/Cell6: R48.2, R66.2, U12.3; also elsewhere on the board
/Battery voltage control/Cell6_ADC: C48.2, R48.1, R54.1; also elsewhere on the board
/Battery voltage control/Cell6_control: U11.1; also elsewhere on the board
GND: C48.1, C49.1, C50.1, C51.1, C52.1, C53.1, R54.2, R55.2, R56.2, R57.2, R58.2, R59.2, R60.2, R61.2, R62.2, R63.2, R64.2, R65.2, U11.3; also elsewhere on the board
unnamed: R60.1, U11.2
unnamed: R61.1, U12.2
unnamed: R62.1, U13.2
unnamed: R63.1, U14.2
unnamed: R64.1, U15.2
unnamed: R65.1, U16.2
unnamed: R66.1, U11.4
unnamed: R67.1, U12.4
unnamed: R68.1, U13.4
unnamed: R69.1, U14.4
unnamed: R70.1, U15.4
unnamed: R71.1, U16.4

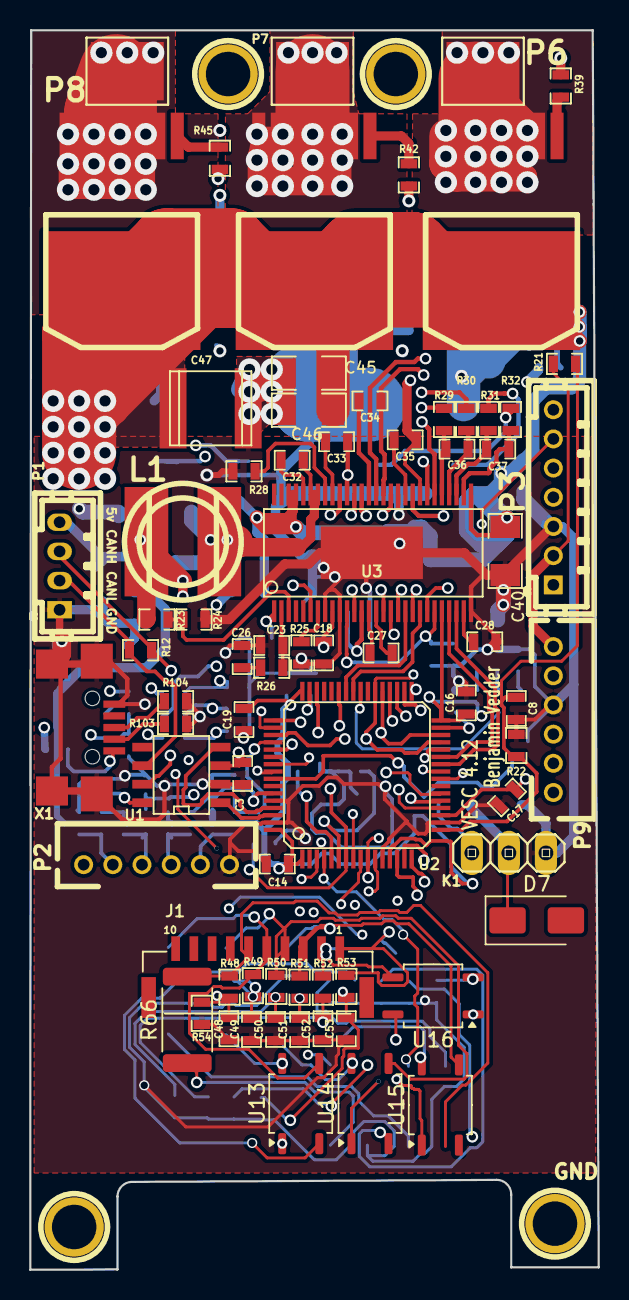
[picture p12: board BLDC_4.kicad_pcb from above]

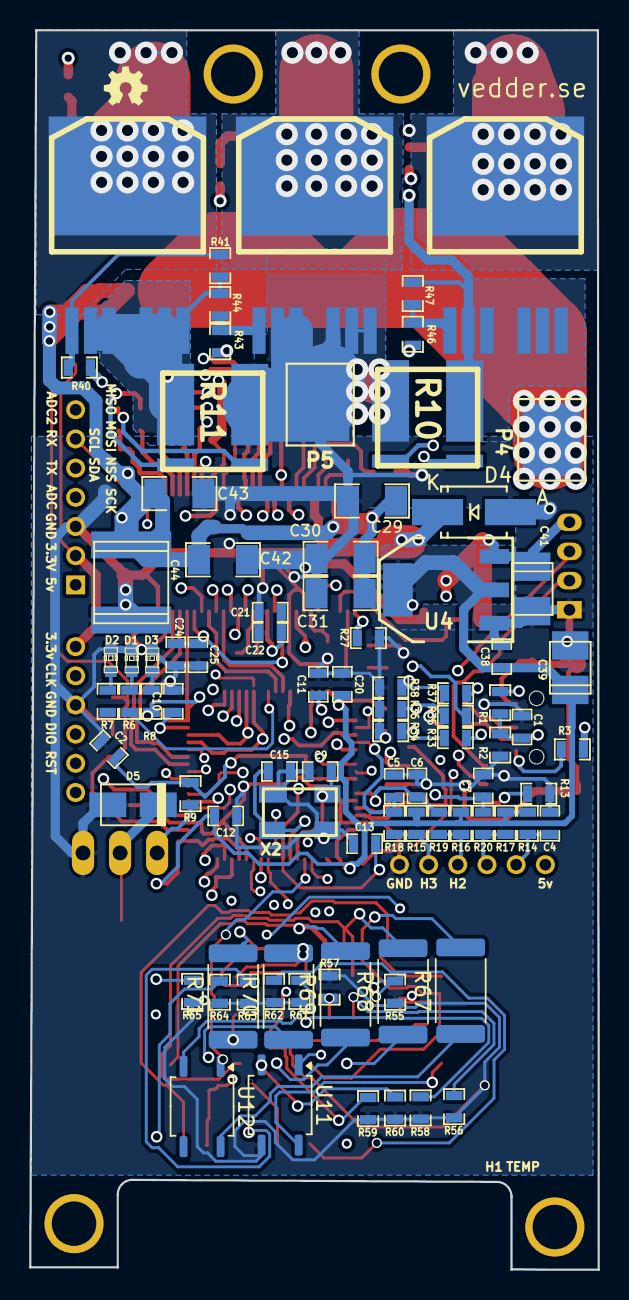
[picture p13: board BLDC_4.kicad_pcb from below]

Board: 4 copper layers, 39.0 x 85.0 mm, 164 parts (86 on the bottom side), 122 nets.

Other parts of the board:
1PIN, 1PIN#2, 1PIN#3, 1PIN#4: P***; 1pin
R3: 0R; SMD-0603_r
X1: MINI-USB-SHIELD-32005-201; USB-UX60R-MB-5ST

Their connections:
+5V: R3.2; also elsewhere on the board
GND: X1.5; also elsewhere on the board
unnamed: R3.1, X1.1

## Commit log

2025-04-03 add battery voltage control
    [BLDC_4-2025-03-20-13-19-51.sch, BLDC_4-2025-03-20-16-30-44.sch, BLDC_4-2025-03-20-19-57-10.sch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]
2025-04-12 added battery balancer
    [BLDC_4.kicad_sch, CAN.kicad_sch, Power.kicad_sch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]
2025-04-12 change resistance for LED resistors
    [BLDC_4.kicad_sch, CAN.kicad_sch, Power.kicad_sch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]
2025-04-24 added usb connector
    [BLDC_4.kicad_pcb, BLDC_4.kicad_sch, CAN.kicad_sch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]
2025-04-24 change diod with usb connector
    [BLDC_4.kicad_sch, CAN.kicad_sch, Power.kicad_sch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]
2025-04-24 started pcb tracing
    [BLDC_4.kicad_pcb]
2025-04-24 added new field in components on battery balancer; pcb tracing
    [BLDC_4.kicad_pcb, BLDC_4.kicad_sch, CAN.kicad_sch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]
2025-05-09 added documentation
    [BLDC_4-B_Cu.dxf, BLDC_4-F_Cu.dxf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]
